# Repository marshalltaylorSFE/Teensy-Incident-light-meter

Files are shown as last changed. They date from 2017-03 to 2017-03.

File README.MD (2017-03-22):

Teensy Incident Light Meter
--------

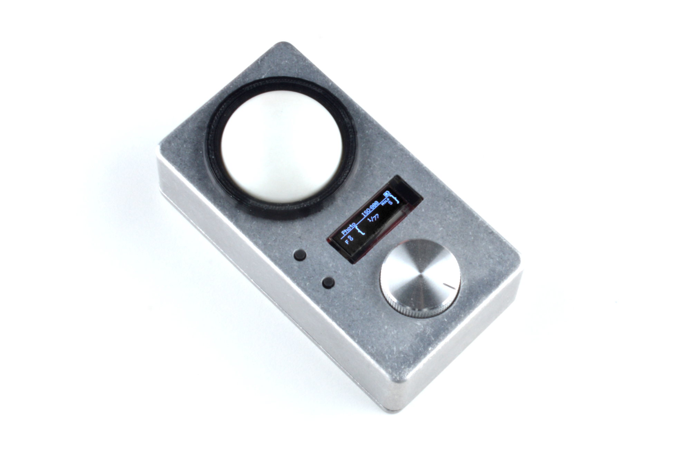
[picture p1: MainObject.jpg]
Product


### Software

Requires the following libraries:

* [Teensyduino](https://www.pjrc.com/teensy/teensyduino.html)
  * Uses included encoder library
* [uCModules library](https://github.com/marshalltaylorSFE/uCModules)
* [TeensyView library](https://github.com/sparkfun/SparkFun_TeensyView_Arduino_Library)
* [TSL2561 library](https://github.com/sparkfun/SparkFun_TSL2561_Arduino_Library)

### Hardware

Uses the following:

* [Teensy 3.2](https://www.sparkfun.com/products/13736)
* [TeensyView](https://www.sparkfun.com/products/14048)
* [TSL2561 Breakout](https://www.sparkfun.com/products/12055)
* [Battery Babysitter](https://www.sparkfun.com/products/13777)
* [1000mAh Lipo](https://www.sparkfun.com/products/13813)
* [Rotary Encoder](https://www.sparkfun.com/products/10596)
* [Knob](https://www.sparkfun.com/products/10001)
* [Tall tack switches (x2)](https://www.sparkfun.com/products/8605)
* [Discrete Semiconductor Kit](https://www.sparkfun.com/products/13682)
* [Resistors](https://www.sparkfun.com/products/10969)
* [Capacitors](https://www.sparkfun.com/products/13698)

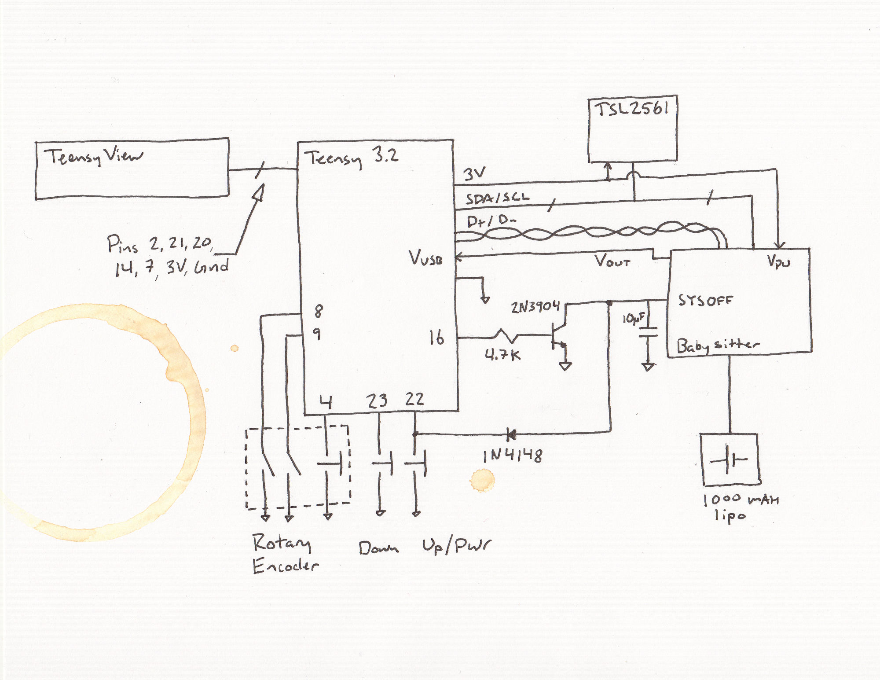
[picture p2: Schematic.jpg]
Schematic


*Schematic diagram.  Click to enlarge.*

### Mechanical

Uses the following:

* [112x61x31mm Enclosure](https://www.sparkfun.com/products/13839)
* [Snappable Breadboard (x2)](https://www.sparkfun.com/products/13268)
* A ping pong ball
* A 3D printed bezel for the ball and light sensor (see /Bezel3DModel)

The 3D model is a bezel for mounting a ping pong ball to a panel.  The model also has screw holes for the light sensor.  Units are in inches, use 2.54 as a ratio for scaling

Case is cut ad-hoc.

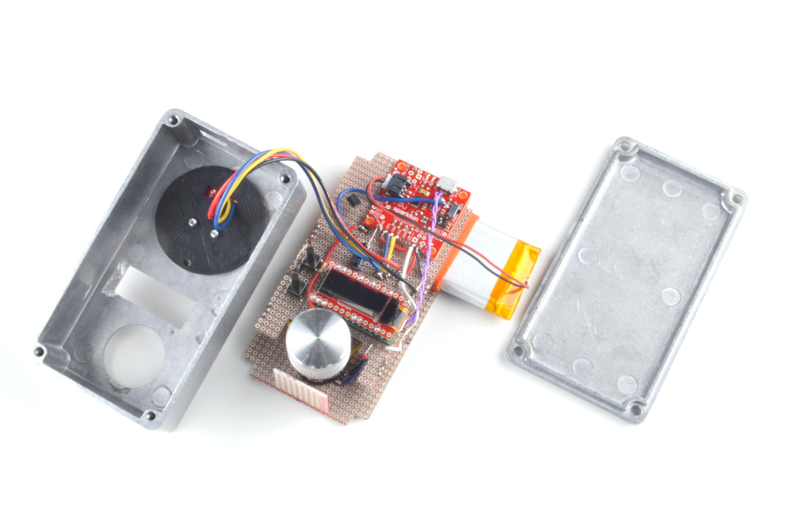
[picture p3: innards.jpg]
Innards


*An assembly*

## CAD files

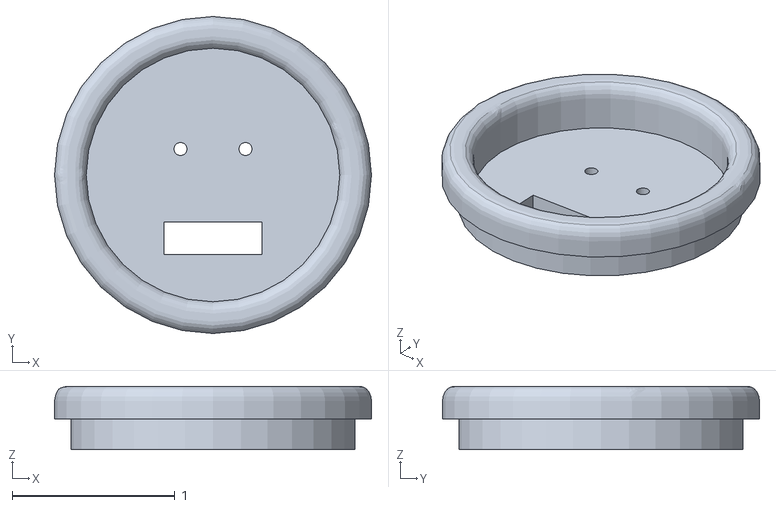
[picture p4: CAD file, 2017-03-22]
Bezel3DModel/PongBezelPrint.stl
1.95 x 1.95 x 0.39

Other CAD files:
Bezel3DModel/001shapes.blend
Bezel3DModel/002FirstTry.blend

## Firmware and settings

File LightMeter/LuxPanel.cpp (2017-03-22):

#include "LuxPanel.h"
#include "panelComponents.h"
#include "LightMeterPanelComponents.h"
#include "HardwareInterfaces.h"
#include "LightMeterHardwareInterfaces.h"
#include <Arduino.h>
#include "TeensyView.h"
#include <SparkFunTSL2561.h>
#include <SparkFunBQ27441.h>

#define KValue 16


extern OLEDFunctions oled;

// Create an SFE_TSL2561 object, here called "light":
extern SFE_TSL2561 light;
extern boolean gain;     // Gain setting, 0 = X1, 1 = X16;
extern unsigned int ms;  // Integration ("shutter") time in milliseconds

const float fStopTable[24] = {1.4, 1.8, 2.0, 2.2, 2.5, 2.8, 3.2, 3.5, 4, 4.5, 5, 5.6, 6.3, 7.1, 8, 9, 10, 11, 13, 14, 16, 18, 20, 22};
const float exposureTable[3] = {0.041666666, 0.033333333, 0.016666666};
const float isoTable[7] = {100, 200, 400, 800, 1600, 3200, 6400};
uint8_t isoTableSize = 7;

extern const uint8_t PIN_POWER_ON = 16;

LuxPanel::LuxPanel( void )
{
	upButton.setHardware(new ArduinoDigitalIn( 22 ), 1);
	add( &upButton );
	
	downButton.setHardware(new ArduinoDigitalIn( 23 ), 1);
	add( &downButton );
	
	encButton.setHardware(new ArduinoDigitalIn( 4 ), 1);
	add( &encButton );

	dataWheel.setHardware(new TeensyEncoderIn( 8, 9 ) );
	add( &dataWheel );
	
	fStopSetting = 7;
	exposureSetting = 1;
	isoSetting = 3;
	state = PInit;
	good = false;
	
	luxAccumulator = 0;
	sampleCount = 0;
	lux = 0;
	
	triggerState = hSRun;
	
	lipoGood = false;
	
}

void LuxPanel::tickStateMachine( int msTicksDelta )
{
	freshenComponents( msTicksDelta );
	
	bool drawDisplay = false;
	unsigned int data0, data1;
	drawDisplay =  oled.drawBatteryWidget();

	//***** PROCESS THE LOGIC *****//
	//Now do the states.
	PState_t nextState = state;
	switch( state )
	{
	case PInit:
		//Can't be running, if button pressed move on
		oled.clear(PAGE);
		drawDisplay = true;
		nextState = PDisplayPhotoValueInit;
		break;
	case PDisplayPhotoValueInit:
		drawDisplay = true;
		oled.clear(PAGE);
		oled.drawMenu("Photo", isoTable[isoSetting], false, true );
		nextState = PDisplayPhotoValue;
		break;
	case PDisplayPhotoValue:
		if( dataWheel.serviceChanged() )
		{
			if( dataWheel.getDiff() > 0 )
			{
				if( fStopSetting < 23 )
				{
					fStopSetting++;
				}
				dataWheel.removeDiff(7);
				
			}
			if( dataWheel.getDiff() < 0 )
			{
				if( fStopSetting > 0 )
				{
					fStopSetting--;
				}
				dataWheel.removeDiff(7);
				
			}
		}
		if( upButton.serviceRisingEdge() )
		{
			nextState = PDisplayVideoValueInit;
		}
		else
		{
			if (light.getData(data0,data1))
			{
				//get the lux
				double tempLux;
				good = light.getLux(gain,ms,data0,data1,tempLux);  // True if neither sensor is saturated
				updateLux( tempLux );
				//exposure time = stop squared * K / ( ISO * Lux )
				float T = pow(fStopTable[fStopSetting],2)*KValue/(lux*(isoTable[isoSetting]));
				oled.eraseLowerArea();
				oled.drawLeftBracket(32,10);
				oled.drawRightBracket(122,10);
				oled.drawFNumStyle1( fStopTable[fStopSetting], 2, 13 );
				oled.drawExposureStyle1( T, 60, 14 );
				if( good == false )
				{
					oled.drawNo( 33, 12 );
				}
				if( triggerState == hSHeld )
				{
					oled.holdStyle1( 100, 10 );
				}
				if( triggerState == hSAveraging )
				{
					oled.aveStyle1( 100, 10 );
				}
				oled.setCursor( 111, 17 );
				oled.print("S");
				drawDisplay = true;
			}
		}
		downButton.serviceRisingEdge();
		break;
	case PDisplayVideoValueInit:
		drawDisplay = true;
		oled.clear(PAGE);
		oled.drawMenu("Video", isoTable[isoSetting], true, true );

		//oled.drawBrackets();
		nextState = PDisplayVideoValue;
		break;
	case PDisplayVideoValue:
		if( dataWheel.serviceChanged() )
		{
			if( dataWheel.getDiff() > 0 )
			{
				if( exposureSetting < 2 )
				{
					exposureSetting++;
				}
				dataWheel.removeDiff(7);
				
			}
			if( dataWheel.getDiff() < 0 )
			{
				if( exposureSetting > 0 )
				{
					exposureSetting--;
				}
				dataWheel.removeDiff(7);
				
			}
		}
		if( downButton.serviceRisingEdge() )
		{
			nextState = PDisplayPhotoValueInit;
		}
		else if( upButton.serviceRisingEdge() )
		{
			nextState = PSetISOInit;
		}
		else
		{
			if (light.getData(data0,data1))
			{
				//get the lux
				double tempLux;
				good = light.getLux(gain,ms,data0,data1,tempLux);  // True if neither sensor is saturated
				updateLux( tempLux );
				//exposure time = stop squared * K / ( ISO * Lux )
				//float T = pow(fStopTable[fStopSetting],2)*KValue/(lux*(isoTable[isoSetting]));
				float N = sqrt((exposureTable[exposureSetting]*lux*isoTable[isoSetting])/KValue);
				oled.eraseLowerArea();
				oled.drawLeftBracket(32,10);
				oled.drawRightBracket(122,10);
				oled.drawExposureStyle2( exposureTable[exposureSetting], 2, 13 );
				oled.drawFNumStyle2( N, 60, 14 );
				if( good == false )
				{
					oled.drawNo( 33, 12 );
				}
				if( triggerState == hSHeld )
				{
					oled.holdStyle1( 100, 10 );
				}
				if( triggerState == hSAveraging )
				{
					oled.aveStyle1( 100, 10 );
				}
				drawDisplay = true;
			}
		}
		break;
	case PSetISOInit:
		dataWheel.clearDiff();
		drawDisplay = true;
		oled.clear(PAGE);
		//menu part
		oled.drawMenu("ISO", true, true );

		//Draw last value
		oled.drawISOScale( isoSetting );
		
		nextState = PSetISO;
		break;
	case PSetISO:
		if( dataWheel.serviceChanged() )
		{
			drawDisplay = true;
			//Erase part
			oled.setCursor(0,11);
			oled.print("      ");
        
			if( dataWheel.getDiff() > 0 )
			{
				if( isoSetting < 6 )
				{
					isoSetting++;
				}
				dataWheel.removeDiff(8);
				
			}
			if( dataWheel.getDiff() < 0 )
			{
				if( isoSetting > 0 )
				{
					isoSetting--;
				}
				dataWheel.removeDiff(8);
				
			}
			//Draw new value
			oled.drawISOScale( isoSetting );
		}
		if( downButton.serviceRisingEdge() )
		{
			nextState = PDisplayVideoValueInit;
		}
		if( upButton.serviceRisingEdge() )
		{
			nextState = pSystemInit;
		}
		break;
	case pSystemInit:
		dataWheel.clearDiff();
		drawDisplay = true;
		oled.clear(PAGE);
		//menu part
		oled.drawMenu("System", true, false );

		//Draw last value
		oled.setCursor(64,11);
		oled.print((float)lipo.voltage()/1000, 2);
		oled.print("V");

		oled.setCursor(0,20);
		oled.print((float)lipo.soc(), 0);
		oled.print("%");
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
